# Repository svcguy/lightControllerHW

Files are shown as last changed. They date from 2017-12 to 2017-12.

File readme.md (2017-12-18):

Schematic and PCB for my workbench light controller

The workbench light is a 1m strip of APA102C Cool White LEDs, 144 LEDS/m.

The controller is a custom PCB that uses capacitive touch buttons and is based on a PIC16F1719

The light housing is made from an aluminum commercial door threshold and some 3/8" black gas piping.

This is a work-in-progress with more information to come

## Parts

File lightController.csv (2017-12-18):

Reference | Value | Footprint | Datasheet | MFN | MFP | S1PN | S1PL | S2PN | S2PL | Description | Source | Critical | Characteristics
J1 | VIN | Terminal_Blocks:TerminalBlock_Altech_AK300-2_P5.00mm | https://media.digikey.com/pdf/Data%20Sheets/Phoenix%20Contact%20PDFs/1935161.pdf | Phoenix Contact | 1935161 | 277-1667-ND | https://www.digikey.com/product-detail/en/phoenix-contact/1935161/277-1667-ND/568614https://www.digikey.com/product-detail/en/phoenix-contact/1935161/277-1667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 | Second Source Part Number | Second Source Part Link | TERM BLOCK PCB 2POS 5.0MM GREEN | ANY | N
C3 | 100uF | Capacitors_SMD:CP_Elec_6.3x5.3 |  | Panasonic | EEE-1CA101WP | PCE3880CT-ND | https://www.digikey.com/product-detail/en/panasonic-electronic-components/EEE-1CA101WP/PCE3880CT-ND/766256 | Second Source Part Number | Second Source Part Link | CAP ALUM 100UF 20% 16V SMD | ANY | N | 6.60mm x 6.60mm x 5.40mm
J2 | LED STRIP | Terminal_Blocks:TerminalBlock_Altech_AK300-4_P5.00mm | https://media.digikey.com/pdf/Data%20Sheets/Phoenix%20Contact%20PDFs/1935187.pdf | Phoenix Contact | 1935187 | 277-1579-ND | https://www.digikey.com/product-detail/en/phoenix-contact/1935187/277-1579-ND/568616 | Second Source Part Number | Second Source Part Link | ~TERM BLOCK PCB 4POS 5.0MM GREEN | ANY | N
C5 | 1000uF | Capacitors_SMD:CP_Elec_8x10.5 |  | Panasonic | EEE-FK0J102P | PCE3763CT-ND | https://www.digikey.com/product-detail/en/panasonic-electronic-components/EEE-FK0J102P/PCE3763CT-ND/766139 | Second Source Part Number | Second Source Part Link | CAP ALUM 1000UF 20% 6.3V SMD | ANY | N | 8.30mm x 8.30mm x 10.50mm
D1 | LED_LIGHT_ON | TO_SOT_Packages_SMD:SOT-23 | http://www.kingbrightusa.com/images/catalog/SPEC/AM23ESGW.pdf | Kingbright | AM23ESGW | 754-1634-1-ND | https://www.digikey.com/product-detail/en/kingbright/AM23ESGW/754-1634-1-ND/4199637 | Second Source Part Number | Second Source Part Link | SOT23 BICOLOR LED | ANY | N | RED-GREEN COMMON CATHODE
D3 | LED_BRIGHT+ | TO_SOT_Packages_SMD:SOT-23 | http://www.kingbrightusa.com/images/catalog/SPEC/AM23ESGW.pdf | Kingbright | AM23ESGW | 754-1634-1-ND | https://www.digikey.com/product-detail/en/kingbright/AM23ESGW/754-1634-1-ND/4199637 | Second Source Part Number | Second Source Part Link | SOT23 BICOLOR LED | ANY | N | RED-GREEN COMMON CATHODE
D5 | LED_BRIGHT- | TO_SOT_Packages_SMD:SOT-23 | http://www.kingbrightusa.com/images/catalog/SPEC/AM23ESGW.pdf | Kingbright | AM23ESGW | 754-1634-1-ND | https://www.digikey.com/product-detail/en/kingbright/AM23ESGW/754-1634-1-ND/4199637 | Second Source Part Number | Second Source Part Link | SOT23 BICOLOR LED | ANY | N | RED-GREEN COMMON CATHODE
D7 | LED_LIGHT_OFF | TO_SOT_Packages_SMD:SOT-23 | http://www.kingbrightusa.com/images/catalog/SPEC/AM23ESGW.pdf | Kingbright | AM23ESGW | 754-1634-1-ND | https://www.digikey.com/product-detail/en/kingbright/AM23ESGW/754-1634-1-ND/4199637 | Second Source Part Number | Second Source Part Link | SOT23 BICOLOR LED | ANY | N | RED-GREEN COMMON CATHODE
SW1 | LIGHT_ON |  |  | DNP | DNP | DNP | DNP | Second Source Part Number | Second Source Part Link | CAP TOUCH PAD | DNP | DNP
SW3 | BRIGHT+ |  |  | DNP | DNP | DNP | DNP | Second Source Part Number | Second Source Part Link | CAP TOUCH PAD | DNP | DNP
SW5 | BRIGHT- |  |  | DNP | DNP | DNP | DNP | Second Source Part Number | Second Source Part Link | CAP TOUCH PAD | DNP | DNP
SW7 | LIGHT_OFF |  |  | DNP | DNP | DNP | DNP | Second Source Part Number | Second Source Part Link | CAP TOUCH PAD | DNP | DNP
D2 | LED_SECT_0 | TO_SOT_Packages_SMD:SOT-23 | http://www.kingbrightusa.com/images/catalog/SPEC/AM23ESGW.pdf | Kingbright | AM23ESGW | 754-1634-1-ND | https://www.digikey.com/product-detail/en/kingbright/AM23ESGW/754-1634-1-ND/4199637 | Second Source Part Number | Second Source Part Link | SOT23 BICOLOR LED | ANY | N | RED-GREEN COMMON CATHODE
D4 | LED_SECT_1 | TO_SOT_Packages_SMD:SOT-23 | http://www.kingbrightusa.com/images/catalog/SPEC/AM23ESGW.pdf | Kingbright | AM23ESGW | 754-1634-1-ND | https://www.digikey.com/product-detail/en/kingbright/AM23ESGW/754-1634-1-ND/4199637 | Second Source Part Number | Second Source Part Link | SOT23 BICOLOR LED | ANY | N | RED-GREEN COMMON CATHODE
D6 | LED_SECT_2 | TO_SOT_Packages_SMD:SOT-23 | http://www.kingbrightusa.com/images/catalog/SPEC/AM23ESGW.pdf | Kingbright | AM23ESGW | 754-1634-1-ND | https://www.digikey.com/product-detail/en/kingbright/AM23ESGW/754-1634-1-ND/4199637 | Second Source Part Number | Second Source Part Link | SOT23 BICOLOR LED | ANY | N | RED-GREEN COMMON CATHODE
D8 | LED_SECT_3 | TO_SOT_Packages_SMD:SOT-23 | http://www.kingbrightusa.com/images/catalog/SPEC/AM23ESGW.pdf | Kingbright | AM23ESGW | 754-1634-1-ND | https://www.digikey.com/product-detail/en/kingbright/AM23ESGW/754-1634-1-ND/4199637 | Second Source Part Number | Second Source Part Link | SOT23 BICOLOR LED | ANY | N | RED-GREEN COMMON CATHODE
SW2 | SECT_0_ON |  |  | DNP | DNP | DNP | DNP | Second Source Part Number | Second Source Part Link | CAP TOUCH PAD | DNP | DNP
SW4 | SECT_1_ON |  |  | DNP | DNP | DNP | DNP | Second Source Part Number | Second Source Part Link | CAP TOUCH PAD | DNP | DNP
SW6 | SECT_2_ON |  |  | DNP | DNP | DNP | DNP | Second Source Part Number | Second Source Part Link | CAP TOUCH PAD | DNP | DNP
SW8 | SECT_3_ON |  |  | DNP | DNP | DNP | DNP | Second Source Part Number | Second Source Part Link | CAP TOUCH PAD | DNP | DNP
U1 | PIC16(L)F1717/9 | Housings_QFP:TQFP-44_10x10mm_Pitch0.8mm | http://ww1.microchip.com/downloads/en/DeviceDoc/40001740B.pdf | Microchip | PIC16F1719-I/PT | PIC16F1719-I/PT-ND | https://www.digikey.com/product-detail/en/microchip-technology/PIC16F1719-I-PT/PIC16F1719-I-PT-ND/4842782 | Second Source Part Number | Second Source Part Link | IC MCU 8BIT 28KB FLASH 44TQFP | SPEC | Y
C1 | 0.1uF | Capacitors_SMD:C_0805_HandSoldering |  | AVX | 08055C104KAT2A | 478-1395-1-ND | https://www.digikey.com/product-detail/en/avx-corporation/08055C104KAT2A/478-1395-1-ND/564427 | Second Source Part Number | Second Source Part Link | CAP CER 0.1UF 50V X7R 0805 | ANY | Y
J3 | ICSP | Connect:Tag-Connect_TC2030-IDC-FP |  | DNP | DNP | DNP | DNP | Second Source Part Number | Second Source Part Link | TAG CONNECT | DNP | DNP
R7 | 1k | Resistors_SMD:R_0805_HandSoldering |  | Yaego | RC0805JR-071KL | 311-1.0KARCT-ND | https://www.digikey.com/product-detail/en/yageo/RC0805JR-071KL/311-1.0KARCT-ND/731165 | Second Source Part Number | Second Source Part Link | RES SMD 1K OHM 5% 1/8W 0805 | ANY | N
R1 | 1k | Resistors_SMD:R_0805_HandSoldering |  | Yaego | RC0805JR-071KL | 311-1.0KARCT-ND | https://www.digikey.com/product-detail/en/yageo/RC0805JR-071KL/311-1.0KARCT-ND/731165 | Second Source Part Number | Second Source Part Link | RES SMD 1K OHM 5% 1/8W 0805 | ANY | N
R8 | 1k | Resistors_SMD:R_0805_HandSoldering |  | Yaego | RC0805JR-071KL | 311-1.0KARCT-ND | https://www.digikey.com/product-detail/en/yageo/RC0805JR-071KL/311-1.0KARCT-ND/731165 | Second Source Part Number | Second Source Part Link | RES SMD 1K OHM 5% 1/8W 0805 | ANY | N
R2 | 1k | Resistors_SMD:R_0805_HandSoldering |  | Yaego | RC0805JR-071KL | 311-1.0KARCT-ND | https://www.digikey.com/product-detail/en/yageo/RC0805JR-071KL/311-1.0KARCT-ND/731165 | Second Source Part Number | Second Source Part Link | RES SMD 1K OHM 5% 1/8W 0805 | ANY | N
R21 | 1k | Resistors_SMD:R_0805_HandSoldering |  | Yaego | RC0805JR-071KL | 311-1.0KARCT-ND | https://www.digikey.com/product-detail/en/yageo/RC0805JR-071KL/311-1.0KARCT-ND/731165 | Second Source Part Number | Second Source Part Link | RES SMD 1K OHM 5% 1/8W 0805 | ANY | N
R23 | 1k | Resistors_SMD:R_0805_HandSoldering |  | Yaego | RC0805JR-071KL | 311-1.0KARCT-ND | https://www.digikey.com/product-detail/en/yageo/RC0805JR-071KL/311-1.0KARCT-ND/731165 | Second Source Part Number | Second Source Part Link | RES SMD 1K OHM 5% 1/8W 0805 | ANY | N
R20 | 1k | Resistors_SMD:R_0805_HandSoldering |  | Yaego | RC0805JR-071KL | 311-1.0KARCT-ND | https://www.digikey.com/product-detail/en/yageo/RC0805JR-071KL/311-1.0KARCT-ND/731165 | Second Source Part Number | Second Source Part Link | RES SMD 1K OHM 5% 1/8W 0805 | ANY | N
R22 | 1k | Resistors_SMD:R_0805_HandSoldering |  | Yaego | RC0805JR-071KL | 311-1.0KARCT-ND | https://www.digikey.com/product-detail/en/yageo/RC0805JR-071KL/311-1.0KARCT-ND/731165 | Second Source Part Number | Second Source Part Link | RES SMD 1K OHM 5% 1/8W 0805 | ANY | N
R6 | 10k | Resistors_SMD:R_0805_HandSoldering |  | Yaego | RC0805JR-0710KL | 311-10KARCT-ND | https://www.digikey.com/product-detail/en/yageo/RC0805JR-0710KL/311-10KARCT-ND/731188 | Second Source Part Number | Second Source Part Link | RES SMD 10K OHM 5% 1/8W 0805 | ANY | N
R19 | 180 | Resistors_SMD:R_0805_HandSoldering |  | Yaego | RC0805JR-07180RL | 311-180ARCT-ND | https://www.digikey.com/product-detail/en/yageo/RC0805JR-07180RL/311-180ARCT-ND/731210 | Second Source Part Number | Second Source Part Link | RES SMD 180 OHM 5% 1/8W 0805 | ANY | N
R18 | 180 | Resistors_SMD:R_0805_HandSoldering |  | Yaego | RC0805JR-07180RL | 311-180ARCT-ND | https://www.digikey.com/product-detail/en/yageo/RC0805JR-07180RL/311-180ARCT-ND/731210 | Second Source Part Number | Second Source Part Link | RES SMD 180 OHM 5% 1/8W 0805 | ANY | N
R15 | 180 | Resistors_SMD:R_0805_HandSoldering |  | Yaego | RC0805JR-07180RL | 311-180ARCT-ND | https://www.digikey.com/product-detail/en/yageo/RC0805JR-07180RL/311-180ARCT-ND/731210 | Second Source Part Number | Second Source Part Link | RES SMD 180 OHM 5% 1/8W 0805 | ANY | N
R14 | 180 | Resistors_SMD:R_0805_HandSoldering |  | Yaego | RC0805JR-07180RL | 311-180ARCT-ND | https://www.digikey.com/product-detail/en/yageo/RC0805JR-07180RL/311-180ARCT-ND/731210 | Second Source Part Number | Second Source Part Link | RES SMD 180 OHM 5% 1/8W 0805 | ANY | N
R17 | 180 | Resistors_SMD:R_0805_HandSoldering |  | Yaego | RC0805JR-07180RL | 311-180ARCT-ND | https://www.digikey.com/product-detail/en/yageo/RC0805JR-07180RL/311-180ARCT-ND/731210 | Second Source Part Number | Second Source Part Link | RES SMD 180 OHM 5% 1/8W 0805 | ANY | N
R16 | 180 | Resistors_SMD:R_0805_HandSoldering |  | Yaego | RC0805JR-07180RL | 311-180ARCT-ND | https://www.digikey.com/product-detail/en/yageo/RC0805JR-07180RL/311-180ARCT-ND/731210 | Second Source Part Number | Second Source Part Link | RES SMD 180 OHM 5% 1/8W 0805 | ANY | N
R9 | 180 | Resistors_SMD:R_0805_HandSoldering |  | Yaego | RC0805JR-07180RL | 311-180ARCT-ND | https://www.digikey.com/product-detail/en/yageo/RC0805JR-07180RL/311-180ARCT-ND/731210 | Second Source Part Number | Second Source Part Link | RES SMD 180 OHM 5% 1/8W 0805 | ANY | N
R10 | 180 | Resistors_SMD:R_0805_HandSoldering |  | Yaego | RC0805JR-07180RL | 311-180ARCT-ND | https://www.digikey.com/product-detail/en/yageo/RC0805JR-07180RL/311-180ARCT-ND/731210 | Second Source Part Number | Second Source Part Link | RES SMD 180 OHM 5% 1/8W 0805 | ANY | N
R28 | 180 | Resistors_SMD:R_0805_HandSoldering |  | Yaego | RC0805JR-07180RL | 311-180ARCT-ND | https://www.digikey.com/product-detail/en/yageo/RC0805JR-07180RL/311-180ARCT-ND/731210 | Second Source Part Number | Second Source Part Link | RES SMD 180 OHM 5% 1/8W 0805 | ANY | N
R27 | 180 | Resistors_SMD:R_0805_HandSoldering |  | Yaego | RC0805JR-07180RL | 311-180ARCT-ND | https://www.digikey.com/product-detail/en/yageo/RC0805JR-07180RL/311-180ARCT-ND/731210 | Second Source Part Number | Second Source Part Link | RES SMD 180 OHM 5% 1/8W 0805 | ANY | N
R26 | 180 | Resistors_SMD:R_0805_HandSoldering |  | Yaego | RC0805JR-07180RL | 311-180ARCT-ND | https://www.digikey.com/product-detail/en/yageo/RC0805JR-07180RL/311-180ARCT-ND/731210 | Second Source Part Number | Second Source Part Link | RES SMD 180 OHM 5% 1/8W 0805 | ANY | N
R25 | 180 | Resistors_SMD:R_0805_HandSoldering |  | Yaego | RC0805JR-07180RL | 311-180ARCT-ND | https://www.digikey.com/product-detail/en/yageo/RC0805JR-07180RL/311-180ARCT-ND/731210 | Second Source Part Number | Second Source Part Link | RES SMD 180 OHM 5% 1/8W 0805 | ANY | N
R24 | 180 | Resistors_SMD:R_0805_HandSoldering |  | Yaego | RC0805JR-07180RL | 311-180ARCT-ND | https://www.digikey.com/product-detail/en/yageo/RC0805JR-07180RL/311-180ARCT-ND/731210 | Second Source Part Number | Second Source Part Link | RES SMD 180 OHM 5% 1/8W 0805 | ANY | N
R3 | 180 | Resistors_SMD:R_0805_HandSoldering |  | Yaego | RC0805JR-07180RL | 311-180ARCT-ND | https://www.digikey.com/product-detail/en/yageo/RC0805JR-07180RL/311-180ARCT-ND/731210 | Second Source Part Number | Second Source Part Link | RES SMD 180 OHM 5% 1/8W 0805 | ANY | N
R4 | 180 | Resistors_SMD:R_0805_HandSoldering |  | Yaego | RC0805JR-07180RL | 311-180ARCT-ND | https://www.digikey.com/product-detail/en/yageo/RC0805JR-07180RL/311-180ARCT-ND/731210 | Second Source Part Number | Second Source Part Link | RES SMD 180 OHM 5% 1/8W 0805 | ANY | N
R5 | 180 | Resistors_SMD:R_0805_HandSoldering |  | Yaego | RC0805JR-07180RL | 311-180ARCT-ND | https://www.digikey.com/product-detail/en/yageo/RC0805JR-07180RL/311-180ARCT-ND/731210 | Second Source Part Number | Second Source Part Link | RES SMD 180 OHM 5% 1/8W 0805 | ANY | N
J4 | DEBUG | Pin_Headers:Pin_Header_Straight_1x04_Pitch2.54mm |  | DNP | DNP | DNP | DNP | Second Source Part Number | Second Source Part Link |  | DNP | DNP
U2 | BTS6143 | TO_SOT_Packages_SMD:TO-252-5_TabPin3 | https://www.infineon.com/dgdl/Infineon-BTS6143D-DS-v01_00-EN.pdf?fileId=5546d4625a888733015aa3da10821022 | Infinieon | BTS6143D | BTS6143DINCT-ND | https://www.digikey.com/product-detail/en/infineon-technologies/BTS6143D/BTS6143DINCT-ND/1557906 | Second Source Part Number | Second Source Part Link | IC SWITCH PWR HISIDE DPAK-5 | ANY | N
R11 | 1 | Resistors_SMD:R_1206_HandSoldering | http://www.yageo.com/documents/recent/PYu-RT_1-to-0.01_RoHS_L_9.pdf | Yaego | RT1206DRD071RL | 311-2927-1-ND | https://www.digikey.com/product-detail/en/yageo/RT1206DRD071RL/311-2927-1-ND/6129346 | Second Source Part Number | Second Source Part Link | RES SMD 1 OHM 0.5% 1/4W 1206 | SPEC | Y | 0.5%
U3 | LM358 | Housings_SOIC:SOIC-8_3.9x4.9mm_Pitch1.27mm | http://www.ti.com/lit/ds/symlink/lm358.pdf | TI | LM358DR | 296-1014-1-ND | https://www.digikey.com/product-detail/en/texas-instruments/LM358DR/296-1014-1-ND/404838 | Second Source Part Number | Second Source Part Link | IC OPAMP GP 700KHZ 8SOIC | ANY | N
R13 | 4.99M | Resistors_SMD:R_0805_HandSoldering |  | Yaego | RMCF0805FT4M99 | RMCF0805FT4M99CT-ND | https://www.digikey.com/product-detail/en/stackpole-electronics-inc/RMCF0805FT4M99/RMCF0805FT4M99CT-ND/2418420 | Second Source Part Number | Second Source Part Link | RES SMD 4.99M OHM 1% 1/8W 0805 | ANY | N | 1%
R12 | 1k | Resistors_SMD:R_0805_HandSoldering |  | Yaego | RC0805FR-071KL | 311-1.00KCRCT-ND | https://www.digikey.com/product-detail/en/yageo/RC0805FR-071KL/311-1.00KCRCT-ND/730391 | Second Source Part Number | Second Source Part Link | RES SMD 1K OHM 1% 1/8W 0805 | ANY | N | 1%
C6 | 0.1uF | Capacitors_SMD:C_0805_HandSoldering |  | AVX | 08055C104KAT2A | 478-1395-1-ND | https://www.digikey.com/product-detail/en/avx-corporation/08055C104KAT2A/478-1395-1-ND/564427 | Second Source Part Number | Second Source Part Link | CAP CER 0.1UF 50V X7R 0805 | ANY | Y
C2 | 0.1uF | Capacitors_SMD:C_0805_HandSoldering |  | AVX | 08055C104KAT2A | 478-1395-1-ND | https://www.digikey.com/product-detail/en/avx-corporation/08055C104KAT2A/478-1395-1-ND/564427 | Second Source Part Number | Second Source Part Link | CAP CER 0.1UF 50V X7R 0805 | ANY | Y
C4 | 0.1uF | Capacitors_SMD:C_0805_HandSoldering |  | AVX | 08055C104KAT2A | 478-1395-1-ND | https://www.digikey.com/product-detail/en/avx-corporation/08055C104KAT2A/478-1395-1-ND/564427 | Second Source Part Number | Second Source Part Link | CAP CER 0.1UF 50V X7R 0805 | ANY | Y

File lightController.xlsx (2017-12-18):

Reference | Value | Footprint | Datasheet | MFN | MFP | S1PN | S1PL | Description | Source | Critical | Characteristics
C1 | 0.1uF | Capacitors_SMD:C_0805_HandSoldering |  | AVX | 08055C104KAT2A | 478-1395-1-ND | https://www.digikey.com/product-detail/en/avx-corporation/08055C104KAT2A/478-1395-1-ND/564427 | CAP CER 0.1UF 50V X7R 0805 | ANY | Y
C2 | 0.1uF | Capacitors_SMD:C_0805_HandSoldering |  | AVX | 08055C104KAT2A | 478-1395-1-ND | https://www.digikey.com/product-detail/en/avx-corporation/08055C104KAT2A/478-1395-1-ND/564427 | CAP CER 0.1UF 50V X7R 0805 | ANY | Y
C3 | 100uF | Capacitors_SMD:CP_Elec_6.3x5.3 |  | Panasonic | EEE-1CA101WP | PCE3880CT-ND | https://www.digikey.com/product-detail/en/panasonic-electronic-components/EEE-1CA101WP/PCE3880CT-ND/766256 | CAP ALUM 100UF 20% 16V SMD | ANY | N | 6.60mm x 6.60mm x 5.40mm
C4 | 0.1uF | Capacitors_SMD:C_0805_HandSoldering |  | AVX | 08055C104KAT2A | 478-1395-1-ND | https://www.digikey.com/product-detail/en/avx-corporation/08055C104KAT2A/478-1395-1-ND/564427 | CAP CER 0.1UF 50V X7R 0805 | ANY | Y
C5 | 1000uF | Capacitors_SMD:CP_Elec_8x10.5 |  | Panasonic | EEE-FK0J102P | PCE3763CT-ND | https://www.digikey.com/product-detail/en/panasonic-electronic-components/EEE-FK0J102P/PCE3763CT-ND/766139 | CAP ALUM 1000UF 20% 6.3V SMD | ANY | N | 8.30mm x 8.30mm x 10.50mm
C6 | 0.1uF | Capacitors_SMD:C_0805_HandSoldering |  | AVX | 08055C104KAT2A | 478-1395-1-ND | https://www.digikey.com/product-detail/en/avx-corporation/08055C104KAT2A/478-1395-1-ND/564427 | CAP CER 0.1UF 50V X7R 0805 | ANY | Y
D1 | LED_LIGHT_ON | TO_SOT_Packages_SMD:SOT-23 | http://www.kingbrightusa.com/images/catalog/SPEC/AM23ESGW.pdf | Kingbright | AM23ESGW | 754-1634-1-ND | https://www.digikey.com/product-detail/en/kingbright/AM23ESGW/754-1634-1-ND/4199637 | SOT23 BICOLOR LED | ANY | N | RED-GREEN COMMON CATHODE
D2 | LED_SECT_0 | TO_SOT_Packages_SMD:SOT-23 | http://www.kingbrightusa.com/images/catalog/SPEC/AM23ESGW.pdf | Kingbright | AM23ESGW | 754-1634-1-ND | https://www.digikey.com/product-detail/en/kingbright/AM23ESGW/754-1634-1-ND/4199637 | SOT23 BICOLOR LED | ANY | N | RED-GREEN COMMON CATHODE
D3 | LED_BRIGHT+ | TO_SOT_Packages_SMD:SOT-23 | http://www.kingbrightusa.com/images/catalog/SPEC/AM23ESGW.pdf | Kingbright | AM23ESGW | 754-1634-1-ND | https://www.digikey.com/product-detail/en/kingbright/AM23ESGW/754-1634-1-ND/4199637 | SOT23 BICOLOR LED | ANY | N | RED-GREEN COMMON CATHODE
D4 | LED_SECT_1 | TO_SOT_Packages_SMD:SOT-23 | http://www.kingbrightusa.com/images/catalog/SPEC/AM23ESGW.pdf | Kingbright | AM23ESGW | 754-1634-1-ND | https://www.digikey.com/product-detail/en/kingbright/AM23ESGW/754-1634-1-ND/4199637 | SOT23 BICOLOR LED | ANY | N | RED-GREEN COMMON CATHODE
D5 | LED_BRIGHT- | TO_SOT_Packages_SMD:SOT-23 | http://www.kingbrightusa.com/images/catalog/SPEC/AM23ESGW.pdf | Kingbright | AM23ESGW | 754-1634-1-ND | https://www.digikey.com/product-detail/en/kingbright/AM23ESGW/754-1634-1-ND/4199637 | SOT23 BICOLOR LED | ANY | N | RED-GREEN COMMON CATHODE
D6 | LED_SECT_2 | TO_SOT_Packages_SMD:SOT-23 | http://www.kingbrightusa.com/images/catalog/SPEC/AM23ESGW.pdf | Kingbright | AM23ESGW | 754-1634-1-ND | https://www.digikey.com/product-detail/en/kingbright/AM23ESGW/754-1634-1-ND/4199637 | SOT23 BICOLOR LED | ANY | N | RED-GREEN COMMON CATHODE
D7 | LED_LIGHT_OFF | TO_SOT_Packages_SMD:SOT-23 | http://www.kingbrightusa.com/images/catalog/SPEC/AM23ESGW.pdf | Kingbright | AM23ESGW | 754-1634-1-ND | https://www.digikey.com/product-detail/en/kingbright/AM23ESGW/754-1634-1-ND/4199637 | SOT23 BICOLOR LED | ANY | N | RED-GREEN COMMON CATHODE
D8 | LED_SECT_3 | TO_SOT_Packages_SMD:SOT-23 | http://www.kingbrightusa.com/images/catalog/SPEC/AM23ESGW.pdf | Kingbright | AM23ESGW | 754-1634-1-ND | https://www.digikey.com/product-detail/en/kingbright/AM23ESGW/754-1634-1-ND/4199637 | SOT23 BICOLOR LED | ANY | N | RED-GREEN COMMON CATHODE
J1 | VIN | Terminal_Blocks:TerminalBlock_Altech_AK300-2_P5.00mm | https://media.digikey.com/pdf/Data%20Sheets/Phoenix%20Contact%20PDFs/1935161.pdf | Phoenix Contact | 1935161 | 277-1667-ND | https://www.digikey.com/product-detail/en/phoenix-contact/1935161/277-1667-ND/568614https://www.digikey.com/product-detail/en/phoenix-contact/1935161/277-1667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 | TERM BLOCK PCB 2POS 5.0MM GREEN | ANY | N
J2 | LED STRIP | Terminal_Blocks:TerminalBlock_Altech_AK300-4_P5.00mm | https://media.digikey.com/pdf/Data%20Sheets/Phoenix%20Contact%20PDFs/1935187.pdf | Phoenix Contact | 1935187 | 277-1579-ND | https://www.digikey.com/product-detail/en/phoenix-contact/1935187/277-1579-ND/568616 | ~TERM BLOCK PCB 4POS 5.0MM GREEN | ANY | N
J3 | ICSP | Connect:Tag-Connect_TC2030-IDC-FP |  | DNP | DNP | DNP | DNP | TAG CONNECT | DNP | DNP
J4 | DEBUG | Pin_Headers:Pin_Header_Straight_1x04_Pitch2.54mm |  | DNP | DNP | DNP | DNP |  | DNP | DNP
R1 | 1k | Resistors_SMD:R_0805_HandSoldering |  | Yaego | RC0805JR-071KL | 311-1.0KARCT-ND | https://www.digikey.com/product-detail/en/yageo/RC0805JR-071KL/311-1.0KARCT-ND/731165 | RES SMD 1K OHM 5% 1/8W 0805 | ANY | N
R10 | 180 | Resistors_SMD:R_0805_HandSoldering |  | Yaego | RC0805JR-07180RL | 311-180ARCT-ND | https://www.digikey.com/product-detail/en/yageo/RC0805JR-07180RL/311-180ARCT-ND/731210 | RES SMD 180 OHM 5% 1/8W 0805 | ANY | N
R11 | 1 | Resistors_SMD:R_1206_HandSoldering | http://www.yageo.com/documents/recent/PYu-RT_1-to-0.01_RoHS_L_9.pdf | Yaego | RT1206DRD071RL | 311-2927-1-ND | https://www.digikey.com/product-detail/en/yageo/RT1206DRD071RL/311-2927-1-ND/6129346 | RES SMD 1 OHM 0.5% 1/4W 1206 | SPEC | Y | 0.50%
R12 | 1k | Resistors_SMD:R_0805_HandSoldering |  | Yaego | RC0805FR-071KL | 311-1.00KCRCT-ND | https://www.digikey.com/product-detail/en/yageo/RC0805FR-071KL/311-1.00KCRCT-ND/730391 | RES SMD 1K OHM 1% 1/8W 0805 | ANY | N | 1%
R13 | 4.99M | Resistors_SMD:R_0805_HandSoldering |  | Yaego | RMCF0805FT4M99 | RMCF0805FT4M99CT-ND | https://www.digikey.com/product-detail/en/stackpole-electronics-inc/RMCF0805FT4M99/RMCF0805FT4M99CT-ND/2418420 | RES SMD 4.99M OHM 1% 1/8W 0805 | ANY | N | 1%
R14 | 180 | Resistors_SMD:R_0805_HandSoldering |  | Yaego | RC0805JR-07180RL | 311-180ARCT-ND | https://www.digikey.com/product-detail/en/yageo/RC0805JR-07180RL/311-180ARCT-ND/731210 | RES SMD 180 OHM 5% 1/8W 0805 | ANY | N
R15 | 180 | Resistors_SMD:R_0805_HandSoldering |  | Yaego | RC0805JR-07180RL | 311-180ARCT-ND | https://www.digikey.com/product-detail/en/yageo/RC0805JR-07180RL/311-180ARCT-ND/731210 | RES SMD 180 OHM 5% 1/8W 0805 | ANY | N
R16 | 180 | Resistors_SMD:R_0805_HandSoldering |  | Yaego | RC0805JR-07180RL | 311-180ARCT-ND | https://www.digikey.com/product-detail/en/yageo/RC0805JR-07180RL/311-180ARCT-ND/731210 | RES SMD 180 OHM 5% 1/8W 0805 | ANY | N
R17 | 180 | Resistors_SMD:R_0805_HandSoldering |  | Yaego | RC0805JR-07180RL | 311-180ARCT-ND | https://www.digikey.com/product-detail/en/yageo/RC0805JR-07180RL/311-180ARCT-ND/731210 | RES SMD 180 OHM 5% 1/8W 0805 | ANY | N
R18 | 180 | Resistors_SMD:R_0805_HandSoldering |  | Yaego | RC0805JR-07180RL | 311-180ARCT-ND | https://www.digikey.com/product-detail/en/yageo/RC0805JR-07180RL/311-180ARCT-ND/731210 | RES SMD 180 OHM 5% 1/8W 0805 | ANY | N
R19 | 180 | Resistors_SMD:R_0805_HandSoldering |  | Yaego | RC0805JR-07180RL | 311-180ARCT-ND | https://www.digikey.com/product-detail/en/yageo/RC0805JR-07180RL/311-180ARCT-ND/731210 | RES SMD 180 OHM 5% 1/8W 0805 | ANY | N
R2 | 1k | Resistors_SMD:R_0805_HandSoldering |  | Yaego | RC0805JR-071KL | 311-1.0KARCT-ND | https://www.digikey.com/product-detail/en/yageo/RC0805JR-071KL/311-1.0KARCT-ND/731165 | RES SMD 1K OHM 5% 1/8W 0805 | ANY | N
R20 | 1k | Resistors_SMD:R_0805_HandSoldering |  | Yaego | RC0805JR-071KL | 311-1.0KARCT-ND | https://www.digikey.com/product-detail/en/yageo/RC0805JR-071KL/311-1.0KARCT-ND/731165 | RES SMD 1K OHM 5% 1/8W 0805 | ANY | N
R21 | 1k | Resistors_SMD:R_0805_HandSoldering |  | Yaego | RC0805JR-071KL | 311-1.0KARCT-ND | https://www.digikey.com/product-detail/en/yageo/RC0805JR-071KL/311-1.0KARCT-ND/731165 | RES SMD 1K OHM 5% 1/8W 0805 | ANY | N
R22 | 1k | Resistors_SMD:R_0805_HandSoldering |  | Yaego | RC0805JR-071KL | 311-1.0KARCT-ND | https://www.digikey.com/product-detail/en/yageo/RC0805JR-071KL/311-1.0KARCT-ND/731165 | RES SMD 1K OHM 5% 1/8W 0805 | ANY | N
R23 | 1k | Resistors_SMD:R_0805_HandSoldering |  | Yaego | RC0805JR-071KL | 311-1.0KARCT-ND | https://www.digikey.com/product-detail/en/yageo/RC0805JR-071KL/311-1.0KARCT-ND/731165 | RES SMD 1K OHM 5% 1/8W 0805 | ANY | N
R24 | 180 | Resistors_SMD:R_0805_HandSoldering |  | Yaego | RC0805JR-07180RL | 311-180ARCT-ND | https://www.digikey.com/product-detail/en/yageo/RC0805JR-07180RL/311-180ARCT-ND/731210 | RES SMD 180 OHM 5% 1/8W 0805 | ANY | N
R25 | 180 | Resistors_SMD:R_0805_HandSoldering |  | Yaego | RC0805JR-07180RL | 311-180ARCT-ND | https://www.digikey.com/product-detail/en/yageo/RC0805JR-07180RL/311-180ARCT-ND/731210 | RES SMD 180 OHM 5% 1/8W 0805 | ANY | N
R26 | 180 | Resistors_SMD:R_0805_HandSoldering |  | Yaego | RC0805JR-07180RL | 311-180ARCT-ND | https://www.digikey.com/product-detail/en/yageo/RC0805JR-07180RL/311-180ARCT-ND/731210 | RES SMD 180 OHM 5% 1/8W 0805 | ANY | N
R27 | 180 | Resistors_SMD:R_0805_HandSoldering |  | Yaego | RC0805JR-07180RL | 311-180ARCT-ND | https://www.digikey.com/product-detail/en/yageo/RC0805JR-07180RL/311-180ARCT-ND/731210 | RES SMD 180 OHM 5% 1/8W 0805 | ANY | N
R28 | 180 | Resistors_SMD:R_0805_HandSoldering |  | Yaego | RC0805JR-07180RL | 311-180ARCT-ND | https://www.digikey.com/product-detail/en/yageo/RC0805JR-07180RL/311-180ARCT-ND/731210 | RES SMD 180 OHM 5% 1/8W 0805 | ANY | N
R3 | 180 | Resistors_SMD:R_0805_HandSoldering |  | Yaego | RC0805JR-07180RL | 311-180ARCT-ND | https://www.digikey.com/product-detail/en/yageo/RC0805JR-07180RL/311-180ARCT-ND/731210 | RES SMD 180 OHM 5% 1/8W 0805 | ANY | N
R4 | 180 | Resistors_SMD:R_0805_HandSoldering |  | Yaego | RC0805JR-07180RL | 311-180ARCT-ND | https://www.digikey.com/product-detail/en/yageo/RC0805JR-07180RL/311-180ARCT-ND/731210 | RES SMD 180 OHM 5% 1/8W 0805 | ANY | N
R5 | 180 | Resistors_SMD:R_0805_HandSoldering |  | Yaego | RC0805JR-07180RL | 311-180ARCT-ND | https://www.digikey.com/product-detail/en/yageo/RC0805JR-07180RL/311-180ARCT-ND/731210 | RES SMD 180 OHM 5% 1/8W 0805 | ANY | N
R6 | 10k | Resistors_SMD:R_0805_HandSoldering |  | Yaego | RC0805JR-0710KL | 311-10KARCT-ND | https://www.digikey.com/product-detail/en/yageo/RC0805JR-0710KL/311-10KARCT-ND/731188 | RES SMD 10K OHM 5% 1/8W 0805 | ANY | N
R7 | 1k | Resistors_SMD:R_0805_HandSoldering |  | Yaego | RC0805JR-071KL | 311-1.0KARCT-ND | https://www.digikey.com/product-detail/en/yageo/RC0805JR-071KL/311-1.0KARCT-ND/731165 | RES SMD 1K OHM 5% 1/8W 0805 | ANY | N
R8 | 1k | Resistors_SMD:R_0805_HandSoldering |  | Yaego | RC0805JR-071KL | 311-1.0KARCT-ND | https://www.digikey.com/product-detail/en/yageo/RC0805JR-071KL/311-1.0KARCT-ND/731165 | RES SMD 1K OHM 5% 1/8W 0805 | ANY | N
R9 | 180 | Resistors_SMD:R_0805_HandSoldering |  | Yaego | RC0805JR-07180RL | 311-180ARCT-ND | https://www.digikey.com/product-detail/en/yageo/RC0805JR-07180RL/311-180ARCT-ND/731210 | RES SMD 180 OHM 5% 1/8W 0805 | ANY | N
SW1 | LIGHT_ON |  |  | DNP | DNP | DNP | DNP | CAP TOUCH PAD | DNP | DNP
SW2 | SECT_0_ON |  |  | DNP | DNP | DNP | DNP | CAP TOUCH PAD | DNP | DNP
SW3 | BRIGHT+ |  |  | DNP | DNP | DNP | DNP | CAP TOUCH PAD | DNP | DNP
SW4 | SECT_1_ON |  |  | DNP | DNP | DNP | DNP | CAP TOUCH PAD | DNP | DNP
SW5 | BRIGHT- |  |  | DNP | DNP | DNP | DNP | CAP TOUCH PAD | DNP | DNP
SW6 | SECT_2_ON |  |  | DNP | DNP | DNP | DNP | CAP TOUCH PAD | DNP | DNP
SW7 | LIGHT_OFF |  |  | DNP | DNP | DNP | DNP | CAP TOUCH PAD | DNP | DNP
SW8 | SECT_3_ON |  |  | DNP | DNP | DNP | DNP | CAP TOUCH PAD | DNP | DNP
U1 | PIC16(L)F1717/9 | Housings_QFP:TQFP-44_10x10mm_Pitch0.8mm | http://ww1.microchip.com/downloads/en/DeviceDoc/40001740B.pdf | Microchip | PIC16F1719-I/PT | PIC16F1719-I/PT-ND | https://www.digikey.com/product-detail/en/microchip-technology/PIC16F1719-I-PT/PIC16F1719-I-PT-ND/4842782 | IC MCU 8BIT 28KB FLASH 44TQFP | SPEC | Y
U2 | BTS6143 | TO_SOT_Packages_SMD:TO-252-5_TabPin3 | https://www.infineon.com/dgdl/Infineon-BTS6143D-DS-v01_00-EN.pdf?fileId=5546d4625a888733015aa3da10821022 | Infinieon | BTS6143D | BTS6143DINCT-ND | https://www.digikey.com/product-detail/en/infineon-technologies/BTS6143D/BTS6143DINCT-ND/1557906 | IC SWITCH PWR HISIDE DPAK-5 | ANY | N
U3 | LM358 | Housings_SOIC:SOIC-8_3.9x4.9mm_Pitch1.27mm | http://www.ti.com/lit/ds/symlink/lm358.pdf | TI | LM358DR | 296-1014-1-ND | https://www.digikey.com/product-detail/en/texas-instruments/LM358DR/296-1014-1-ND/404838 | IC OPAMP GP 700KHZ 8SOIC | ANY | N

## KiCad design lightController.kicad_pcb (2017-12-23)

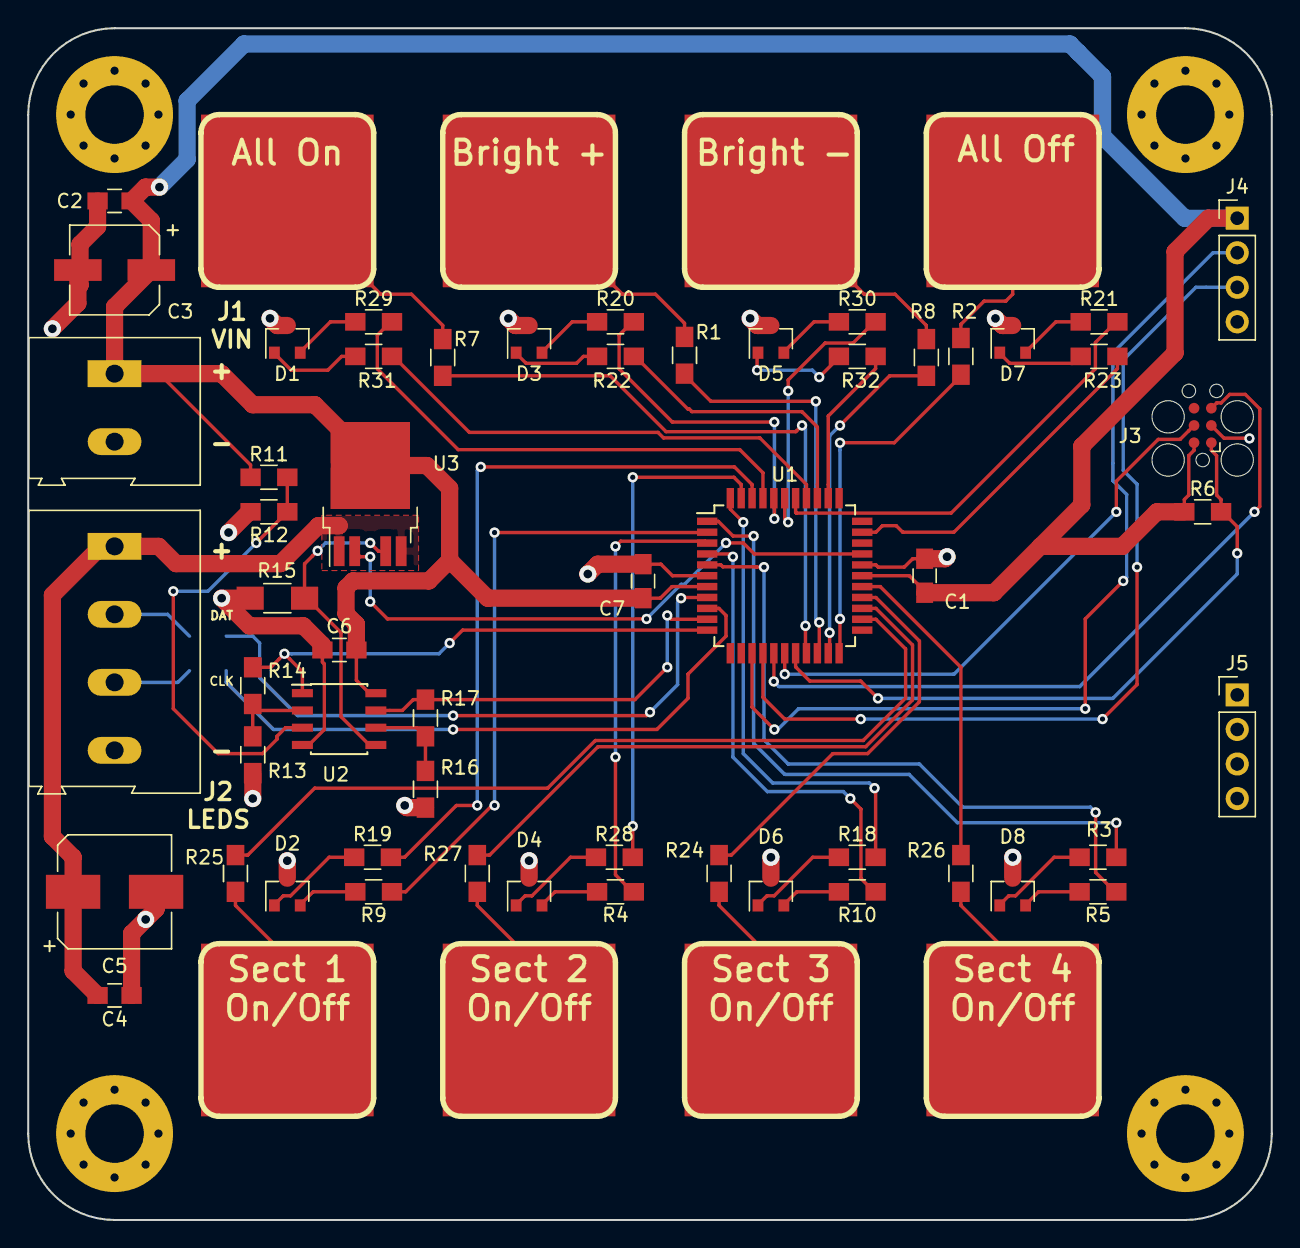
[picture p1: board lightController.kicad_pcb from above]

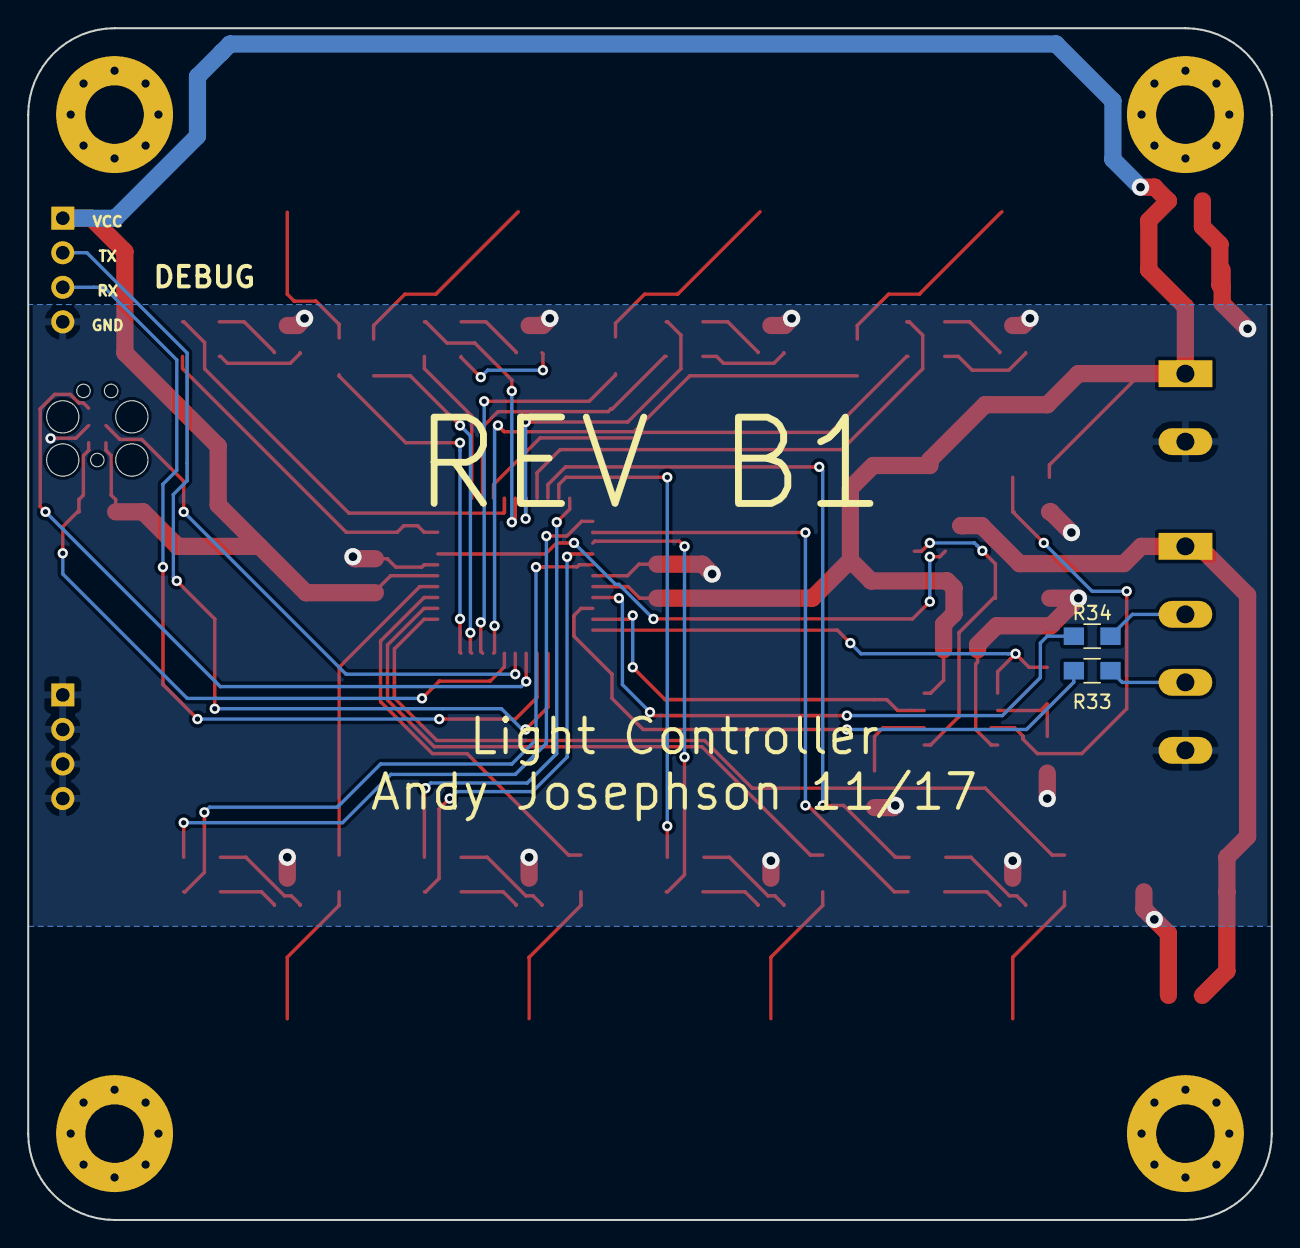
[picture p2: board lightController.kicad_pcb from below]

Board: 2 copper layers, 91.4 x 87.6 mm, 69 parts (2 on the bottom side), 67 nets.

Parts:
C1, C2, C4, C6, C7: 0.1uF; C_0805_HandSoldering
C3: 100uF; CP_Elec_6.3x5.3
C5: 1000uF; CP_Elec_8x10.5
D1: LED_LIGHT_ON; SOT-23
D2: LED_SECT_0; SOT-23
D3: LED_BRIGHT+; SOT-23
D4: LED_SECT_1; SOT-23
D5: LED_BRIGHT-; SOT-23
D6: LED_SECT_2; SOT-23
D7: LED_LIGHT_OFF; SOT-23
D8: LED_SECT_3; SOT-23
H1, H2, H3, H4: HOLE; MountingHole_4.3mm_M4_Pad_Via
J1: VIN; TerminalBlock_Altech_AK300-2_P5.00mm
J2: LED STRIP; TerminalBlock_Altech_AK300-4_P5.00mm
J3: ICSP; Tag-Connect_TC2030-IDC-FP
J4: DEBUG; Pin_Header_Straight_1x04_Pitch2.54mm
J5: GND; Pin_Header_Straight_1x04_Pitch2.54mm
R1, R2, R7, R8, R16, R24, R25, R26, R27, R33, R34: 1k; R_0805_HandSoldering
R3, R4, R5, R9, R10, R18, R19, R20, R21, R22, R23, R28, R29, R30, R31, R32: 180; R_0805_HandSoldering
R6: 10k; R_0805_HandSoldering
R11: 90.9k; R_0805_HandSoldering
R12: 90.9; R_0805_HandSoldering
R13: 1.1k; R_0805_HandSoldering
R14: 110k; R_0805_HandSoldering
R15: 1k; R_1206_HandSoldering
R17: 4.02k; R_0805_HandSoldering
SW1: LIGHT_ON; CAP_SENSE_PAD
SW2: SECT_0_ON; CAP_SENSE_PAD
SW3: BRIGHT+; CAP_SENSE_PAD
SW4: SECT_1_ON; CAP_SENSE_PAD
SW5: BRIGHT-; CAP_SENSE_PAD
SW6: SECT_2_ON; CAP_SENSE_PAD
SW7: LIGHT_OFF; CAP_SENSE_PAD
SW8: SECT_3_ON; CAP_SENSE_PAD
U1: PIC16(L)F1717/9; TQFP-44_10x10mm_Pitch0.8mm
U2: LM358; SOIC-8_3.9x4.9mm_Pitch1.27mm
U3: BTS6143; TO-252-5_TabPin3

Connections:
/CAP1: R7.2, SW1.1
/CAP2: R1.2, SW3.1
/CAP3: R8.2, SW5.1
/CAP4: R2.2, SW7.1
/CAP5: R25.1, SW2.1
/CAP6: R27.1, SW4.1
/CAP7: R24.1, SW6.1
/CAP8: R26.1, SW8.1
/DEBUG1: J4.2, U1.14
/DEBUG2: J4.3, U1.15
/I_SNS: R17.1, U1.10, U2.7
/LED_1_G: D1.2, R29.1
/LED_1_R: D1.1, R31.1
/LED_2_G: D3.2, R20.1
/LED_2_R: D3.1, R22.1
/LED_3_G: D5.2, R30.1
/LED_3_R: D5.1, R32.1
/LED_4_G: D7.2, R21.1
/LED_4_R: D7.1, R23.1
/LED_5V: C4.2, C5.1, J2.1, U3.1, U3.5
/LED_5_G: D2.2, R9.2
/LED_5_R: D2.1, R19.1
/LED_6_G: D4.2, R4.2
/LED_6_R: D4.1, R28.1
/LED_7_G: D6.2, R10.2
/LED_7_R: D6.1, R18.1
/LED_8_G: D8.2, R5.2
/LED_8_R: D8.1, R3.2
/LED_CLK: R33.1, U1.9
/LED_DAT: R34.1, U1.8
/PGC: J3.5, U1.16
/PGD: J3.4, U1.17
/PWR_EN: U1.30, U3.2
/V_SNS: R14.1, U1.11, U2.1
/~MCLR: J3.1, R6.2, U1.18
GND: C1.2, C2.1, C3.2, C4.1, C5.2, C6.1, C7.2, D1.3, D2.3, D3.3, D4.3, D5.3, D6.3, D7.3, D8.3, J1.2, J2.4, J3.3, J4.4, J5.1, J5.2, J5.3, J5.4, R12.2, R13.1, R15.2, R16.1, U1.6, U1.29, U2.4
unnamed: J2.2, R34.2
unnamed: J2.3, R33.2
unnamed: R1.1, U1.20
unnamed: R2.1, U1.22
unnamed: R3.1, U1.1
unnamed: R4.1, U1.3
unnamed: R5.1, U1.5
unnamed: R7.1, U1.19
unnamed: R8.1, U1.21
unnamed: R9.1, U1.2
unnamed: R10.1, U1.4
unnamed: R11.2, R12.1, U2.3
unnamed: R13.2, R14.2, U2.2
unnamed: R15.1, U2.5, U3.4
unnamed: R16.2, R17.2, U2.6
unnamed: R18.2, U1.44
unnamed: R19.2, U1.42
unnamed: R20.2, U1.40
unnamed: R21.2, U1.38
unnamed: R22.2, U1.36
unnamed: R23.2, U1.32
unnamed: R24.2, U1.26
unnamed: R25.2, U1.24
unnamed: R26.2, U1.27
unnamed: R27.2, U1.25
unnamed: R28.2, U1.43
unnamed: R29.2, U1.41
unnamed: R30.2, U1.39
unnamed: R31.2, U1.37
unnamed: R32.2, U1.35
VCC: C1.1, C2.2, C3.1, C6.2, C7.1, J1.1, J3.2, J4.1, R6.1, R11.1, U1.7, U1.28, U2.8, U3.3

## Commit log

2017-12-18 Initial Commit of version A1 files
    [lightController.csv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]
2017-12-20 Changed R15 and R17 to make current sense work
    [lightController.sch]
2017-12-23 Changed TX/RX to PORTB and I_SNS and PWR_EN accordingly Added SPI termination resistor footprints Added J5 GND pads
    [lightController.kicad_pcb, lightController.sch]
